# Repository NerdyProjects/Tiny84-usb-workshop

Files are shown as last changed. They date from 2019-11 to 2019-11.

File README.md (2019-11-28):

# Lötworkshop: Bau dir einen kleinen Arduino (oder beginne den Weg dorthin)

Dieses Projekt beschreibt eine kleine Schaltung welche als Bausatz mit verschiedenen Ausbaustufen vorgesehen für absolute Anfänger zum Erlernen von Lötfertigkeiten dienen soll.
Menschen, welche weiter in die Thematik einsteigen möchten, erhalten in der letzten Ausbaustufe ein kleines Arduino-kompatibles Experimentierboard, für das einfach eigene Software geschrieben werden kann.

Diese Anleitung geht hauptsächlich auf Board-spezifische Details ein. Es ist empfohlen, das Löten gemeinsam mit erfahrenen Menschen durchzuführen, welche eine Einführung ins Löten geben und bei Problemen für Hilfestellung da sind.

[Weiter zur Minimalbestückung](bestueck/1_minimum.md)
[Weiter zur 2. Ausbaustufe: Interaktivität](bestueck/2_interactive.md)
[Weiter zur 3. Ausbaustufe: Alternative Stromversorgung](bestueck/3_usb_power.md)
[Weiter zur 4. Ausbaustufe: Arduino](bestueck/4_usb.md)

# (Solder) workshop: Building a tiny, USB capable microcontroller board

## Part list
Start with the absolute minimum and add all the parts you like. If you got this as a workshop kit, your microcontroller should be preprogrammed to do something with just the LED, so you don't need to care about anything else than soldering the components.

If you want to change the code or use a brand new microcontroller, you need some more parts or even a second arduino acting as a programmer. Read on later.
### Absolute minimum
* BT1: Coin cell battery holder, KZH 20-1
* A CR2032 (or similar) 3V Lithium battery to power the board. Put that in when you are done soldering.
* C1: 100 nF THT ceramic capacitor. Optionally, chose a 0805 or 0603 SMD capacitor.
* C2: 4.7µF (or a bit bigger) polarized capacitor (grid 2.5mm). Care: The part has the "-" side marked - that is the filled side on the pcb. The voltage of the capacitor does not matter.
* U2: 14 pin THT IC socket (PDIP-14). This is not necessary but strongly recommended to be able to easily exchange the microcontroller.
* U2: ATTiny84A microcontroller. Choose the one in a 14 pin DIP package.
* D7: 3mm LED: red, green or yellow. Blue/White likely don't work because they need more than 3V.
* R7: 470 ohms resistor - anything from 100-1000 ohms work. It is used to limit the LED current.
* JP1: Either solder a 2 or 3 pin header and use a jumper on pins 2-3 to switch the power on or permanently connect pins 2 and 3 with a piece of wire or tin.

### Some more LEDs
* D6: Another 3mm LED (2)
* R6: Another 470 ohms resistor for the other LED
* D5: Another 3mm LED (3)
* R5: Another 470 ohms resistor

### Some buttons
* SW1 and SW2: 6 or 12mm push buttons

### A buzzer
* A piezo buzzer (7.6mm grid) - SUMMER EPM 121

### Powering the board through USB instead
* JP1: Finally use a 3 pin header here - 1-2 choses USB power, 2-3 choses battery power
* J2: USB B socket - USB BW
* D3 and D4: Any normal diode like 1N4148 to lower the 5V USB voltage a bit.
  * if you don't want to go on and use USB data transfer or external parts, you can use a solder bridge instead, as the board is fine with 5V.

### Allround power supply: 3,5-30 V or USB or Battery
* Remove D3 and D4 and leave them open
* D1, D2: Use any normal diode like 1N4148 so the board uses either an external power or USB - depending on what's available
* U1: LP2950-3.3 a voltage regulator in TO92 package (any other 3.3 V regulator in that package is also fine - 100 mA is enough)

### Changing the microcontrollers software: Get creative!
* D3/D4 need to be in place, alternatively the all-round power supply.
* R1/R2: 68 ohms resistors in series with the USB data lines
* R3: 1.5 kilo ohms resistor that pulls up USB D- to signal the computer that we are a low speed USB device

### Connect some stuff: Pin headers
* Be aware of the voltage external components are compatible with! This board is designed to be operated with 3.3 V as soon as you use USB. Do not connect external 5V input signals!
* Put a 9 pin and a 8 pin header to reach all IO of the microcontroller and put some external hardware to it via jumper wires.
* Put a 4 pin header on the I2C header to connect for example a BME280 temperature sensor shield directly.
  * You likely need R4 and R8 I2C pullup resistors. 2.2 kOhms up to 10 kOhms are probably fine.

### Analog voltage inputs
* Optionally put C3 - another 100 nF ceramic capacitor. This allows better quality analog voltage readings configuring the ADC with external capacitor at Aref.

### Fucked up? 6 pin AVR in system program connector
* solder a 2x3 pin header on the ISP to be able to use a ISP adapter. Alternatively, you can use jumper wires and another Arduino as an ISP adapter, all the ISP pins are available at the other pin headers as well.

## Errata
* Ceramic capacitor footprints are too small for the big capacitors I have
* LED silk screen does not indicate direction (can use Pin1 = square or direction towards ATTiny as GND)
* Experimental area is made from vias that don't have solder mask clearance

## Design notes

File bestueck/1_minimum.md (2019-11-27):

# Minimalbestückung

Die Minimalbestückung ermöglicht dir, das Löten kennenzulernen. Du benötigst lediglich eine handvoll Bauteile und hast nach Abschluss deiner Arbeiten eine Schaltung zusammengebaut, welche mehrere LEDs blinken lässt und von dir ein und ausgeschaltet werden kann.

## Bauteilliste
* BT1: Batteriehalter für CR2032 Knopfzelle, Reichelt KZH 20-1
* Eine CR2032 Knopfzelle (3V)
* C1, C6: 100 nF Kondensator (RM2.5), Reichelt KERKO 100N
* C2: 4.7µF Elektrolytkondensator (RM2.5), Reichelt RAD 104 4,7/100. Einbaurichtung beachten.
* U2: 14 poliger IC Sockel, Reichelt GS 14. Kann weggelassen werden, wird aber dringend empfohlen.
* U2: ATTiny84A-PU Mikrocontroller, Reichelt: ATTINY 84A-PU. Hinweis: Sollte vorprogrammiert sein, damit deine Schaltung etwas tut.
* D5/D6/D7: 3mm LEDs gelb/grün/rot oder beliebige Farben. Einbaurichtung beachten.
* R5/R6/R7: 470 ohm Widerstand (gelb-violett-braun--gold), Reichelt 1/4W 470
* JP1: Stiftleiste 2 oder 3 polig + Steckbrücke, um die Pins 2-3 zum Einschalten zu verbinden

## Bestücken

Bestückungsplan

Die Position der Bauteile kannst du vom Bestückungsdruck und/oder diesen Bestückungsplan ablesen.
Fange am besten mit den Widerständen an, da dies die unempfindlichsten Bauteile sind.

* Lege den Widerstand an seine Position und merke dir, wo die Beinchen geknickt werden müssen, damit er passend und schön sitzt
* Biege die Beinchen mit einer Spitzzange im 90 Grad Winkel
* Stecke den Widerstand an seine Position. Damit er beim Löten nicht herausfällt, kannst du die Beinchen an der Unterseite etwas auseinanderbiegen
* Erwärme die Lötstelle für 1-2 Sekunden mit dem Lötkolben. Achte dabei darauf, die Lötspitze möglichst flächig aufzulegen, um einen guten Wärmeübergang von der Lötspitze zum Pad auf der Platine aber auch zum Beinchen des Widerstands zu bekommen
* Führe etwas Lötzinn hinzu. Soviel, dass die Lötstelle sich ein kleines bisschen wölbt, aber keine richtige Kugel wird.
* Entferne den Lötkolben wieder und prüfe dein Ergebnis

Anschließend kannst du die Kondensatoren einlöten. Achte bei C2, dem Elektrolytkondensator, darauf, dass dieser richtig herum eingebaut werden muss. Auf der Platine ist die "+" Seite mit einem kleinen Plus-Zeichen markiert, die "-" Seite dick schwarz ausgemalt. Der Kondensator selbst hat eine Markierung an der "-" Seite.
Die Keramikkondensatoren C1 und C6 musst du eventuell noch passend biegen. Nutze dazu wieder eine Spitzzange.

Löte dann die LEDs ein. Auch hier ist die Richtung wieder relevant: Eine Seite der LED ist am Gehäuse leicht abgeflacht, gleichzeitig ist dieses Beinchen etwas kürzer. Im Bestückungsplan ist diese Seite der LED als Linie statt Kreisbogen markiert, es ist die Seite, welche zum Mikrocontroller U2 hinzeigt.

Als letztes lötest du eine 2- oder 3-polige Stiftleiste für JP1, den Batteriehalter BT1 und den IC Sockel U2 ein.

Prüfe abschließend deine Platine:
* Sehen alle Lötstellen gleichmäßig und ähnlich aus?
* Sind Lötbrücken entstanden, die Kurzschlüsse erzeugen?
* Sind alle Bauteile am richtigen Ort?
* Sind alle Bauteile richtigherum (Elko, LEDs, Batteriehalter)?

Nun kannst du den Mikrocontroller U2 in den Sockel einsetzen. Sei dabei vorsichtig, keine Pins zu verbiegen. Eine Seite ist mit einer Kerbe markiert, diese findest du im Sockel sowie auf der Platine wieder. Setze den IC richtig herum ein!

Als letzten Schritt sezt du die Batterie BT1 ein. Achte darauf, sie richtig herum einzusetzen, die Schaltung verfügt über keinen Verpolschutz und geht dann kaputt.

Wenn du bei der Stiftleiste die beiden rechten Pins, 2+3, mit einem Jumper verbindest, sollten die LEDs anfangen zu blinken.

Herzlichen Glückwunsch! Du hast deine ersten Löterfahrungen gemacht. Lust auf mehr? In weiteren Teilen dieses Workshops kannst du weitere Teile hinzufügen, um mit deiner Schaltung zu interagieren, statt einer Batterie den USB Port als Stromversorgung zu benutzen oder gar eigene Anwendungen auf den Mikrocontroller zu spielen - quasi deinen eigenen Arduino zu bauen.

Auch wenn das Blinken der LED so wunderschön anzusehen ist, solltest du den Jumper oder die Batterie entfernen, wenn du es nicht sehen möchtest. Die Batterielaufzeit beträgt ungefähr 80 Stunden LED-leuchten, bei dem vorprogrammierten Blinkmuster aller 3 LEDs also etwa 5 Tage. Tu der Umwelt also etwas gutes und schalte das Gerät aus, wenn du es nicht benötigst.

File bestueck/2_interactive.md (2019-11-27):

# Interaktivbestückung

So eine blinkende LED ist ja was feines, aber wäre es nicht schöner, mit der Schaltung zu kommunizieren?
Bauen wir doch einfach zwei Taster hinzu.

# Bauteilliste
* SW1, SW2: Taster 6mm oder Taster 12mm (z.B. Reichelt RND 210-00191)

# Bestücken

Bestückungsplan

Vor dem Bestücken solltest du die Schaltung ausschalten und zusätzlich sicherheitshalber die Batterie entfernen.
Setze den Taster in die Mitte des jeweiligen Feldes auf - auf der Platine sind Löcher für 6mm und 12mm Taster vorgesehen, deswegen bleiben 4 Löcher frei.

# Spielen
Schaltest du die Schaltung wieder ein, so siehst du das gewohne Blinken.
Drückst du Schalter "SW1" etwas länger (knapp 1s), so schaltest du zwischen 3 Modi um:
* Modus 1 (nach Einschalten): Alle 3 LEDs blinken
* Modus 2: LED3 blinkt. LED1 wird durch kurzes Drücken von SW1 aktiviert, LED2 wird durch kurzes Drücken von SW2 aktiviert
* Modus 3: LED3 blinkt langsam. LED1 und 2 leuchten, lassen sich durch SW1/SW2 kurz ausschalten

Schau im nächsten Teil, um deine Schaltung per USB zu versorgen.

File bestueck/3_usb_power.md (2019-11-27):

# Stromversorgung per USB
Schön, dass du weitermachen magst. In diesem Teil erweitern wir deine Schaltung mit einem USB Anschluss, um nicht ständig die Batterie tauschen zu müssen. Zusammen mit einem alten Handyladekabel eignet sich die Schaltung dann auch dazu, wochenlang eingeschaltet in der Ecke zu liegen.

An dieser Stelle ist es ratsam, dass du dich entscheidest:
Möchtest du eventuell noch weiter machen und bald deinen Mikrocontroller auch selbst programmieren? Dann gehe am besten zur "Luxusvariante" B.
Du bist dir sicher, dass es dann jetzt auch bald reicht? Dann löte entweder Variante A oder Variante B. Es spielt für dich keine Rolle, A ist etwas einfacher zu löten.

# Variante A: Dioden statt Spannungsregler

Diese Schaltung ist zum Betrieb mit einer Spannung von 2-3V vorgesehen und unterstützt damit später auch den Anschluss zur Datenübertragung per USB mit dem Computer.
Da der USB Port uns jedoch 5V liefert, müssen die restlichen 2V irgendwo hin. In dieser Variante verwenden wir die Dioden D3 und D4 hierzu:
Dioden sind sogenannte Halbleiter. Sie lassen den Strom nur in eine Richtung fließen. Leider kommt dies aber zu einem Preis: "normale" Siliziumdioden haben eine Flussspannung von etwa 0,7 V - sprich diese Spannung fällt an der Diode ab und steht für die Schaltung dahinter nicht zur Verfügung. Genau diesen Effekt machen wir uns hier zu nutze - Spannungsregelung "mal ganz einfach".

## Bauteile
* J2: USB B Buchse, Reichelt USB BW
* D3, D4: Standard Silizium Diode (z.B. 1N4148). Polung beachten

## Bestückung

Bestückungsplan

Fange am besten mit den Dioden an. Ein Strich auf dem Gehäuse markiert die negative Seite: "+" wird auf der anderen Seite angelegt und in die Seite des Strichs durchgeleitet. Schließt du den Strom andersherum an (oder vertauschst die Richtung der Diode), so sperrt die Diode. Die Schaltung bleibt aus. Wissensübertragung: LEDs, LeuchtDIODEN, sind ebenfalls Halbleiter und haben diese Eigenschaft einer Diode. Deswegen leuchtet eine LED auch nur, wenn der Strom "in die richtige Richtung fließt".

Abschließend lötest du die USB Buchse auf. Die großen Löcher mit den Metallclips dienen der zusätzlichen mechanischen Stabilität. Du kannst diese etwas umbiegen und mit einer größeren Menge Lötzinn verlöten, sodass die Buchse mechanisch belastbarer wird.

# Variante B: Ein richtiger Spannungsregler

In Variante A behelfen wir uns mittels zweier Dioden, um die benötigte Versorgungsspannung unserer Schaltung zu erzeugen. Wir haben gelernt: Eine Diode lässt etwa 0,7V abfallen. Was nun aber, wenn wir garnicht wissen, wie unsere Eingangsspannung ist? Wenn wir unsere Schaltung vielleicht von einer 12V Batterie versorgen wollen?

Glücklicherweise gibt es für diese häufige Anforderung eine Lösung - einen Spannungsregler. Als integriertes Bauteil enthält er in seinem Gehäuse ganz klein viele Transistoren, Widerstände und Kapazitäten. Diese "Magie" machen wir uns hier zu nutzen, um unsere Schaltung mit stabilen 3,3V versorgen zu können, wenn wir sie über USB versorgen.

Zum sicheren Betrieb benötigen viele Spannungsregler einen Kondensator am Ein- sowie Ausgang. Diese sorgen dafür, dass der Spannungsregler nicht anfängt zu schwingen.

## Bauteile
* J2: USB B Buchse, Reichelt USB BW
* D2: Standard Silizium Diode (z.B. 1N4148). Polung beachten
* U1: LP2950-3.3 Festspannungsregler 3,3V TO92, Reichelt LP 2950 ACZ3,3
* C7: Elektrolytkondensator 4,7µF RM2,5
* C8: Keramikkondensator 100 nF

## Bestückung
Bestückungsplan

Mit den meisten Bauteilen solltest du schon zurecht kommen. Der Spannungsregler U1 besitzt 3 Beinchen, die etwas dichter zusammen sind, als du das schon kennst. Sei hier besonders gründlich, dass nach dem Zusammenbau keine Beinchen vebrunden sind. Passiert dir das ausversehen doch, so kann es entgegen des Gefühlt sinnvoll sein, nocheinmal etwas Lötzinn hinzuzugeben: Im Lötzinn ist Flussmittel enthalten, welches das Lötzinn schön an die Stellen fließen lässt, wo es hin soll. Flussmittel geht leider beim längeren Erhitzen - also beim Löten - kaputt. Hilft das nicht, lass dir eine Entlötpumpe sowie gegebenenfalls Entlötlitze zeigen.
Achtung: Der Spannungsregler ist das erste Bauteil, was wirklich Hitzeempfindlich ist. Du solltest es nicht länger als 10 Sekunden mit dem Lötkolben erhitzen und dann eine Pause von mindestens einer halben Minute einlegen.

## weitere Optionen der Spannungsversorgung
Für weitere Optionen bietet dein Board die Stiftleisten links (J4) und rechts (J5). Auf J4 findest du ganz oben "Vext", was soviel wie externe Stromversorgung heißt. Wenn du die Diode D1 ebenfalls mit einer 1N4148 bestückst, so kannst du hier eine Spannung von bis zu 24V anlegen und deine Schaltung damit versorgen.
Die Dioden D1 und D2 sorgen dafür, dass du gleichzeitig USB und eine externe Versorgung anschließen kannst. Es wird die Versorgung mit der höheren Spannung verwendet.

# Betrieb
Nun bekommt der "Schalter" JP1 eine weitere Bedeutung:
* Verbindest du die beiden linken Pins, 1 und 2, so wird deine Schaltung per USB (oder optional externer Versorgung) versorgt.
* Verbindest du die beiden rechten Pins, 2 und 3, so wird deine Schaltung von der Batterie versorgt.
* Auch wenn das schwer möglich ist, achte bitte darauf, niemals alle 3 Pins (bzw. Pins 1 und 3) miteinander zu verbinden. Du würdest dann die Batterie "aufladen" - das nehmen Lithium Knopfzellen dir übel und werden auslaufen. Das ist weder gut für die Umwelt, noch für das Gemüt.

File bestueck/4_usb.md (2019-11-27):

# Kommunikation mit dem Computer

Diese Schaltung ist dafür vorbereitet, mit dem Computer verbunden zu werden. Einerseits, damit du deine eigenen Programme aufspielen kannst, andererseits kannst du sie auch als "USB Gadget" verwenden, beispielsweise eine USB Tastatur, die automatisch deine Visitenkarte eintippt, sobald sie angeschlossen wird. Hierzu benötigen wir noch ein paar Bauteile.

# Bauteilliste
* R1, R2: 68 Ohm Widerstand, Reichelt 1/4W 68: blau-grau-schwarz--gold
* R3: 1,5 kOhm Widerstand, Reichelt 1/4W 1k5: braun-grün-rot--gold (Im Kit eventuell 1,8 kOhm beiliegend: braun-grau-schwarz-braun--braun)

Bestückungsplan
# Benutzen

Dieser Abschnitt muss leider noch geschrieben werden... Kurz für die Erfahrenen:
Der ATTiny ist mit dem Micronucleus Bootloader vorprogrammiert. Der Bootloader wird durch Drücken von SW1 während des Einschaltens aktiviert.
Benutze ATTinyCore in der Arduino IDE um Programme für den ATTiny84 zu erstellen. Die Taktfrequenz beträgt 1 MHz - du kannst den Prescaler in der Software umstellen, um 8 MHz zu bekommen (Achtung: Im Batteriebetrieb könnte das zu Problemen führen). Das Programmieren kannst du mittels der micronucleus-CLI machen, ich möchte dir allerdings in naher Zukunft dafür eine eigene Arduino Integration über ein Board bieten.

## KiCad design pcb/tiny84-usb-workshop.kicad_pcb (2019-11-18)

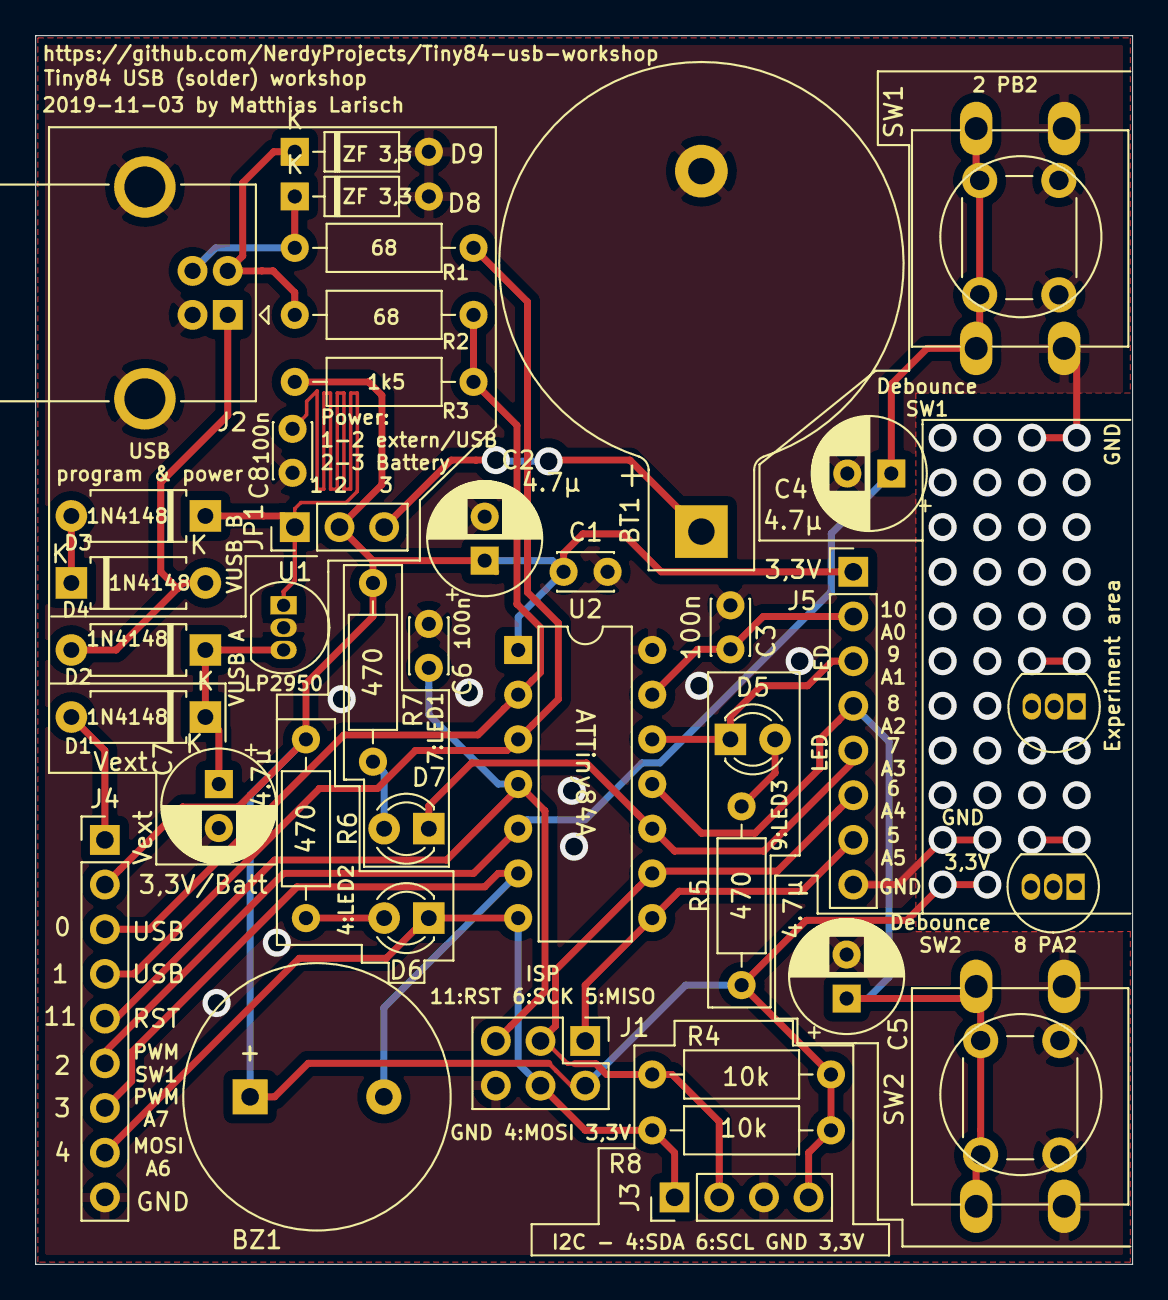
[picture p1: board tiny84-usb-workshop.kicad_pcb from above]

Board: 2 copper layers, 62.4 x 69.9 mm, 41 parts (0 on the bottom side), 25 nets.

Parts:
BT1: Battery_Cell; BatteryHolder_Keystone_103_1x20mm
BZ1: Buzzer; Buzzer_15x7.5RM7.6
C1, C3, C6, C8: 100n; C_Disc_D3.0mm_W2.0mm_P2.50mm
C2, C4, C5, C7: 4.7µ; CP_Radial_D6.3mm_P2.50mm
D1, D2, D3, D4: 1N4148; D_A-405_P7.62mm_Horizontal
D5: LED3; LED_D3.0mm
D6: LED2; LED_D3.0mm
D7: LED1; LED_D3.0mm
D8, D9: ZF 3,3; D_DO-35_SOD27_P7.62mm_Horizontal
J1: Conn_02x03_Odd_Even; PinHeader_2x03_P2.54mm_Vertical
J2: USB_B; USB_B_OST_USB-B1HSxx_Horizontal
J3: I2C; PinHeader_1x04_P2.54mm_Vertical
J4: Conn_01x09; PinHeader_1x09_P2.54mm_Vertical
J5: Conn_01x08; PinHeader_1x08_P2.54mm_Vertical
JP1: Jumper_3_Open; PinHeader_1x03_P2.54mm_Vertical
Q1, Q2: BC547; TO-92_Inline
R1, R2: 68; R_Axial_DIN0207_L6.3mm_D2.5mm_P10.16mm_Horizontal
R3: 1k5; R_Axial_DIN0207_L6.3mm_D2.5mm_P10.16mm_Horizontal
R4, R8: 10k; R_Axial_DIN0207_L6.3mm_D2.5mm_P10.16mm_Horizontal
R5, R6, R7: 470; R_Axial_DIN0207_L6.3mm_D2.5mm_P10.16mm_Horizontal
SW1: BTN1; SW_PUSH-12mm
SW2: BTN2; SW_PUSH-12mm
SW3, SW4: SW_Push; SW_PUSH_6mm
U1: LP2950-3.3_TO92; TO-92_Inline
U2: ATtiny84A-PU; DIP-14_W7.62mm

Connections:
+3V3: BZ1.1, C1.1, C2.1, J1.2, J3.4, J4.2, J5.1, JP1.2, R3.2, R4.2, R5.1, R6.1, R7.1, R8.2, U2.1
GND: BT1.2, C1.2, C2.2, C3.1, C4.2, C5.2, C6.2, C7.2, C8.2, D8.2, D9.2, J1.6, J2.4, J2.5, J3.3, J4.9, J5.8, SW1.2, SW2.2, SW3.2, SW4.2, U1.2, U2.14
MISO: J1.1, J5.7, U2.8
MOSI: D6.1, J1.4, J3.1, J4.8, R8.1, U2.7
unnamed: BT1.1, JP1.3
unnamed: C7.1, D1.1, D2.1, U1.3
unnamed: C8.1, D3.1, JP1.1, U1.1
unnamed: D2.2, D4.2, J2.1
unnamed: D3.2, D4.1
unnamed: D5.2, R5.2
unnamed: D6.2, R6.2
unnamed: D7.2, R7.2
unnamed: D8.1, J2.3, R1.2
unnamed: D9.1, J2.2, R2.2
PA0: C3.2, J5.2, U2.13
PA1: D5.1, J5.3, U2.12
PA2: C5.1, J5.4, SW2.1, SW4.1, U2.11
PA3: D7.1, J5.5, U2.10
PA7: BZ1.2, J4.7, U2.6
PB2: C4.1, J4.6, SW1.1, SW3.1, U2.5
RESET: C6.1, J1.5, J4.5, U2.4
SCK: J1.3, J3.2, J5.6, R4.1, U2.9
USB_D+: J4.4, R1.1, U2.3
USB_D-: J4.3, R2.1, R3.1, U2.2
VDC: D1.2, J4.1

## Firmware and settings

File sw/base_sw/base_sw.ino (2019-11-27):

#include <avr/sleep.h>
#define LED_1 7
#define LED_2 4
#define LED_3 9
#define BUTTON_1 2
#define BUTTON_2 8

volatile uint32_t wdticks;
volatile uint8_t btn_press;
volatile uint8_t btn_state;
volatile uint8_t btn_rpt;

/* key debounce:
 *  one bit per key. Initial: state 0, ct 1. implements a 1-bit counter with CT
 *  (chose 1bit version here because WDT interval is quite long)
 *  pressed: state 0, ct 1; b 1 -> ct ~(1&1)=0, b=1&0=0, state 0, pressed |= 0
 *  pressed: state 0, ct 0; b 1 -> ct ~(0&1)=1, b=1, state 1, pressed |= 1
 *  pressed: state 1, ct 0; b 0 -> ct ~(1&0)=1, b=0, state 1, pressed |= 0
 *  pressed: state 1, ct 1; b 0 -> ct ~(1&1)=0, b=0, state 1, pressed |= 0
 *  unpressed: state 1, ct 0, b 1 -> ct ~(0&1)=1, b=1, state 0, pressed |= 0
 *  pressed: state 0, ct 1, b 1 -> ct ~(1&1)=0, b=0, state 0
 */
ISR(WDT_vect)
{
  static uint8_t ct0 = 0xFF, ct1 = 0xFF, rpt;
  uint8_t b = btn_state;
  wdticks++;
  if(!digitalRead(BUTTON_1)) {
    b ^= 1;
  }
  if(!digitalRead(BUTTON_2)) {
    b ^= 2;
  }
  ct0 = ~(ct0 & b);
  //ct1 = ct0 ^ (ct1 & b);
  b &= ct0;// & ct1;         
  btn_state ^= b;
  btn_press |= btn_state & b;  
  if(!btn_state) {
    rpt = 10;
  }
  if(--rpt == 0) {
    rpt = 10;
    btn_rpt = btn_state;
  }
}

uint32_t getWdticks(void) {
  uint32_t t;
  cli();
  t = wdticks;
  sei();
  return t;
}

ISR(PCINT1_vect) {
}

ISR(PCINT0_vect) {
}

void led(uint8_t led, bool state) {
  uint8_t pin;
  switch(led) {
    case 1:
      pin = LED_1;
      break;
    case 2:
      pin = LED_2;
      break;
    case 3:
      pin = LED_3;
      break;
    default:
      return;
  }
  digitalWrite(pin, !state);
}

void powerdown() {
  set_sleep_mode(SLEEP_MODE_PWR_DOWN);
  sleep_enable();
  sleep_mode();
  sleep_disable();
}

void setup() {
  led(1, false);
  led(2, false);
  led(3, false);
  pinMode(LED_1, OUTPUT);
  pinMode(LED_2, OUTPUT);
  pinMode(LED_3, OUTPUT);
  pinMode(BUTTON_1, INPUT_PULLUP);
  pinMode(BUTTON_2, INPUT_PULLUP);
  cli();
  // Set the watchdog reset bit in the MCU status register to 0.
  MCUSR &= ~(1<<WDRF);  
  // Allow changes of watchdog configuration
  WDTCSR |= (1<<WDCE) | (1<<WDE);
  // Set watchdog clock prescaler bits to a value of 64ms
  // Enable watchdog as interrupt only (no reset).
  WDTCSR = (1<<WDP1) | (1<<WDIE);
  sei();
}

bool readKey(int key) {
  if(btn_press & key) {
    btn_press &= ~key;
    return true;
  }
  return false;
}

bool readKeyLong(int key) {
  if(btn_rpt & key) {
    btn_rpt &= ~key;
    return true;
  }
  return false;
}

void loop() {
  static uint8_t mode = 0;
  uint32_t tick = getWdticks();
  if(readKeyLong(1)) {
    mode++;
    if(mode > 3) {
      mode = 0;
    }
  }
  switch(mode) {
    case 0:
    led(3, (tick & 0x07) == 0x05);
    led(2, (tick & 0x03) == 0x03);
    led(1, (tick & 0x03) == 0x00);
    break;
    case 1:
    led(3, (tick & 0x0F) == 0x09);
    led(2, readKey(2));
    led(1, readKey(1));
    break;
    case 2:
    led(3, (tick & 0x1F) == 0x11);
    led(2, !readKey(2));
    led(1, !readKey(1));
    break;
    default:
    break;    
  }
  
  powerdown();
}

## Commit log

2019-11-03 initial PCB, WIP
    [tiny84-usb-workshop.kicad_pcb, tiny84-usb-workshop.sch]
2019-11-03 silkscreen adjustments
    [tiny84-usb-workshop.kicad_pcb, tiny84-usb-workshop.sch]
2019-11-03 finish pcb v1
    [tiny84-usb-workshop.kicad_pcb, tiny84-usb-workshop.sch]
2019-11-03 fix voltage regulator caps
    [tiny84-usb-workshop.kicad_pcb, tiny84-usb-workshop.sch]
2019-11-03 Fix missing annotation
    [tiny84-usb-workshop.sch]
2019-11-18 PCB + errata
    [tiny84-usb-workshop.kicad_pcb, tiny84-usb-workshop.sch]
2019-11-27 Update software/schematic version
    [tiny84-usb-workshop.sch]
